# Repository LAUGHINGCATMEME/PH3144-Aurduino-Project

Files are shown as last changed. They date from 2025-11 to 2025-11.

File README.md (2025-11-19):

# How to use this repo

If someone wants to do the same then do it in the follwoing order: 
- Learn how each components works & why it's used
- Read datasheet
- Use the code, Schematics and report as a refrence, not as a guide.

### PS
Everything in this report is written by me other than the code for aurduinos. I have used grammerly as an assistant for grammer correction after completing the report entirely. Much of the code is written by AI though I woudn't suggest anyone to do the same.

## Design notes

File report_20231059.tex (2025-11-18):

\documentclass[%
sor,
jor,
amsmath,amssymb,
reprint,
]{revtex4-2}
\usepackage{rotating}
\usepackage{url}
\usepackage{hyperref}

\usepackage{amsmath, amssymb, amsfonts}
\usepackage{siunitx}
\usepackage{graphicx}

\begin{document}
\title{Arduino Project Report}

\author{Aumshree P. Shah - Group 19\\20231059}
\altaffiliation{\color{red}aumshree.pinkalbenshah@students.iiserpune.ac.in}
\date{\today}
\begin{abstract}
	\centering
	This report contains the motivation, idea, workings, troubleshooting, and final model of the Arduino project of Group-19.
\end{abstract}
\maketitle
\tableofcontents
\vspace*{\fill}
\pagebreak
\section{Motivation and Idea}
\subsection{Motivation}
Although given that the final product should be related to safety and address a safety issue, which my following concept does, I also tried to make something out of the ordinary, which motivates us to learn the workings of Arduino. 
\subsection{Concept}

My final concept was to make a \textit{Remote Controlled car, equipped with sensors to detect threats and monitor/neutralize them with a coil gun and cameras}. Though I went through many different concepts, like: Water gun with precise aim at fire, Car with automatic fire detection and neutralization, Dog in hostel detection and monitoring air quality levels, I decided to finalize on my former idea due to its complexity, budget constraints, and other reasons.

\section{Workings and Troubleshooting}
\subsection{Finding Resources}
The idea of \textit{RC car with Arduino} and \textit{Coilgun controlled by Arduino} separately has been worked on by many people many times. The diagrams and schematics of them, as well as the code, are available on the web and can be found easily, though there isn't much I could find that combines both of these ideas. Hence, although I had many of the resources readily available for my help, learning how it is done and making the changes was indeed very labour-intensive. I have made my own schematics for both the Transceiver and Receiver in the following section.
\subsection{Schematics}
First, we shall look at the transmitter schematic as shown in FIG-1.

\begin{sidewaysfigure}
	\centering
	
	\caption{Tramsitter Schematics}
	\label{fig:transmitter}
\end{sidewaysfigure}
Here we see the connection from the NRF module to the specific pins is done in such a way that allows the most compatibility. For example, in Arduino Nano, pins D13, D12, and D11 act as SCK, MISO, and MOSI, respectively. Other connections are arbitrary. The Joystick X and Y pins are connected to analog pins. The power is transmitted across the components in the following way: 
$$\text{Battery (6V)} \implies \text{Aurduino Nano (5V)} \implies \text{NRF Module regulator (3.3V)} \implies \text{NRF Module}$$\\
Now we will look at the receiver schematics shown in FIG-2. Here, although the NRF is connected in the same way to the Arduino, a few connections are made because of pin support; for example, the ENA pin is connected to D9 because only a few D pins support PWM, which the L298 driver requires. The power is transmitted across the components in the following way: 

\begin{align*}
	\text{Battery (11.1V)} \implies &\text{L298N Motor Driver(11.1)} \implies \text{4 x Motors}\\
					&\text{L298N Motor Driver(5V)} \implies \text{Aurduino Nano (5V))} \implies \text{NRF Module w/Regulator}
\end{align*}
\begin{sidewaysfigure}
	\centering
	
	\caption{Reciver Schematics}
	\label{fig:reciver}
\end{sidewaysfigure}

\subsection{How I made it}
Since my main goal was to make a RC-controlled car, my first step was to make two different Arduinos communicate. For the communication, I decided to use \textbf{NRF24L01+PA+LNA SMA Antenna Wireless Transceiver communication module} as the price difference between the alternatives v/s this was not much, whereas the range was significantly higher. This module operates at 3.3V, to regulate it, I used \textbf{NRF24L01 regulator}, which regulates the logic voltage. I used this regulator after trial and error to regulate the voltage, which will be discussed in a later section.\\

For the motors, I use \textbf{4 x 300RPM PO Motors} since 300 RPM seemed in the proper range for a car with wheels of diameter $\approx 7\si{cm}$. These motors run on 12V. \\

For the battery, in the transmitter I used \textbf{4 x 1.5V alkaline battery} giving 6V, which is given to Arduino $V_{in}$ pin. The Arduino has an internal regulator that regulates it to 5V. The Arduino provides power to the NRF regulator.\\ 

In the receiver, I used \textbf{3 x 3.7V LiOH battery}, which is rechargeable. The reason for using them will be discussed in the next section. This produces a voltage of $\approx 11$V, which is given to \textbf{L298N Motor Driver}, which runs the motors. The L298N has an internal regulator that regulates the voltage to 5V, which powers the Arduino.\\

A phone holder is added to the back, which can function as many things. \\

In the receiver, the NRF is also powered by Arduino through a regulator. Almost all of the connections are made using \textbf{Jumper wires of different types} and \textbf{Breadboard}. Some do use \textbf{High Gauge copper wires} to supply high current to motors.\\
\subsection{Issues I faced - and how I solved them}
\subsubsection{Battery unable to provide required power}
Initially, I used \textbf{9V alkaline battery}. A single 9V battery was unable to provide power to the motors, so I used 4 of them in parallel. Although this made the car functional, it had many disadvantages. For example, it was unrechargeable, even 4 of them in series were sometimes not able to provide enough current, and the motors were rated for 12V, so 9V batteries weren't running the motors at maximum capacity.
\subsubsection{Search for a proper chassis for a car}
I needed a strong base for my car. A cardboard couldn't hold its weight. A proper chassis was really hard to find, and after some trial and error, I finally settled on a small black metal box, which I found in a mechanic's box. 
\subsubsection{Regulation of NRF module}
This was a really big issue when I first started testing, since to make anything out of this project, I first had to communicate between two Arduinos. The NRF module operates at 3.3V, and the Arduino logic is 5V. I had to use some kind of way to regulate it. First, I used resistor dividers, but it turned out that they caused a high level of signal disturbance. Then I used voltage regulators, these kind of worked, but there was always some kind of issue which made the modules unable to communicate. Also, since the NRF module needs a large supply of current peaks, my initial tests were without parallel capacitors, so no matter how I regulated the voltage, the module was unable to communicate. This was finally resolved by using a dedicated NRF voltage regulator, which was compact, cheap, and did everything we needed.
\subsubsection{Fused and non-working components}
Many of the components got fused while I were working on them, includes but not limited to: Arduino nano, an NRF module, etc. To prevent this from happening on other components, I found the following helpful: Not soldering components directly to the other components, using voltage limiters, reading the datasheet (obvious, but I initially ignored this), and by not shorting the components (obvious, but that's how my nano got fused).
\subsubsection{Weight, Speed Structure and Battery life}
For weight, Speed, and battery life, all these issues were solved by LiOH batteries. To fix the motor ot the chassis, I used Feviquick, which worked really well and was able to carry a good amount of weight on the car. Other components were fixed by hot glue, and the final structure was made after many trials and errors.\\

\section{Result and final product}
The car and the controller looked like this after completion:\\

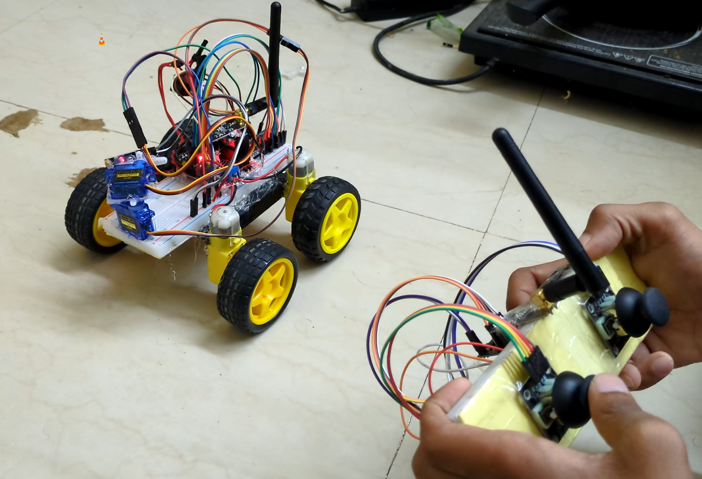
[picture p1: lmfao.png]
\linebreak

and video's of this running is uploaded on youtube as refrenced in the next refrence section. 
\vspace{1cm}
\hrule
\vfill
\pagebreak

\bibliographystyle{apsrev4-2}  % or apsrev4-1, prsty, etc.
\nocite{*}
\bibliography{resource}

\end{document}

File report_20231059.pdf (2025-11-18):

## Arduino Project Report

Aumshree P. Shah - Group 19 20231059a)

(Dated: 18 November 2025)
Synopsis

This report contains the motivation, idea, workings, troubleshooting, and final model of the Arduino project of Group-19.

CONTENTS

I. Motivation and Idea | 2
A. Motivation | 2
B. Concept | 2
II. Workings and Troubleshooting | 2
A. Finding Resources | 2
B. Schematics | 2
C. How I made it | 5
D. Issues I faced - and how I solved them | 5
1. Battery unable to provide required power | 5
2. Search for a proper chassis for a car | 5
3. Regulation of NRF module | 5
4. Fused and non-working components | 6
5. Weight, Speed Structure and Battery life | 6
III. Result and final product | 6
References | 7

a)aumshree.pinkalbenshah@students.iiserpune.ac.in

I. MOTIVATION AND IDEA
A. Motivation

Although given that the final product should be related to safety and address a safety issue, which my following concept does, I also tried to make something out of the ordinary, which motivates us to learn the workings of Arduino.

B. Concept

My final concept was to make a Remote Controlled car, equipped with sensors to detect threats and monitor/neutralize them with a coil gun and cameras. Though I went through many different concepts, like: Water gun with precise aim at fire, Car with automatic fire detection and neutralization, Dog in hostel detection and monitoring air quality levels, I decided to finalize on my former idea due to its complexity, budget constraints, and other reasons.

II. WORKINGS AND TROUBLESHOOTING

A. Finding Resources

The idea of RC car with Arduino and Coilgun controlled by Arduino separately has been worked on by many people many times. The diagrams and schematics of them, as well as the code, are available on the web and can be found easily, though there isn’t much I could find that combines both of these ideas. Hence, although I had many of the resources readily available for my help, learning how it is done and making the changes was indeed very labour-intensive. I have made my own schematics for both the Transceiver and Receiver in the following section.

B. Schematics

First, we shall look at the transmitter schematic as shown in FIG-1.
Here we see the connection from the NRF module to the specific pins is done in such a way that allows the most compatibility. For example, in Arduino Nano, pins D13, D12, and D11 act as SCK, MISO, and MOSI, respectively. Other connections are arbitrary. The Joystick X and Y pins are connected to analog pins. The power is transmitted across the components in the following way:

Battery (6V) =⇒ Aurduino Nano (5V) =⇒ NRF Module regulator (3.3V) =⇒ NRF Module

Now we will look at the receiver schematics shown in FIG-2. Here, although the NRF is connected in the same way to the Arduino, a few connections are made because of pin support; for example, the ENA pin is connected to D9 because only a few D pins support PWM, which the L298 driver requires. The power is transmitted across the components in the following way:

Battery (11.1V) =⇒ L298N Motor Driver(11.1) =⇒ 4 x Motors
L298N Motor Driver(5V) =⇒ Aurduino Nano (5V)) =⇒ NRF Module w/Regulator

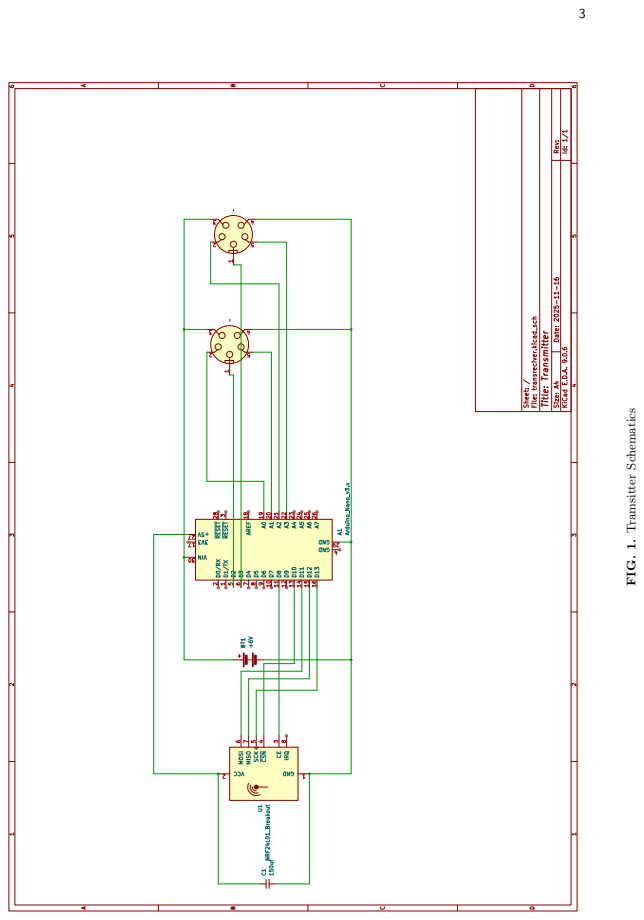
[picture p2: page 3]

FIG. 1. Tramsitter Schematics

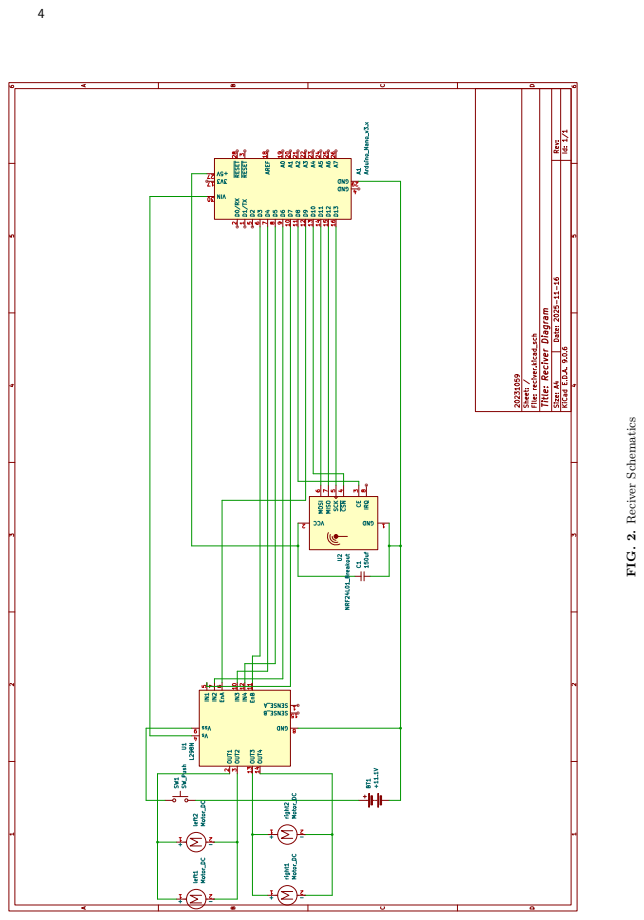
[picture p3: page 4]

FIG. 2. Reciver Schematics

C. How I made it

Since my main goal was to make a RC-controlled car, my first step was to make two different Arduinos communicate. For the communication, I decided to use NRF24L01+PA+LNA SMA Antenna Wireless Transceiver communication module as the price difference between the alternatives v/s this was not much, whereas the range was significantly higher. This module operates at 3.3V, to regulate it, I used NRF24L01 regulator, which regulates the logic voltage. I used this regulator after trial and error to regulate the voltage, which will be discussed in a later section.

For the motors, I use 4 x 300RPM PO Motors since 300 RPM seemed in the proper range for a car with wheels of diameter ≈ 7cm. These motors run on 12V.

For the battery, in the transmitter I used 4 x 1.5V alkaline battery giving 6V, which is given to Arduino Vin pin. The Arduino has an internal regulator that regulates it to 5V. The Arduino provides power to the NRF regulator.

In the receiver, I used 3 x 3.7V LiOH battery, which is rechargeable. The reason for using them will be discussed in the next section. This produces a voltage of ≈ 11V, which is given to L298N Motor Driver, which runs the motors. The L298N has an internal regulator that regulates the voltage to 5V, which powers the Arduino.

A phone holder is added to the back, which can function as many things.

In the receiver, the NRF is also powered by Arduino through a regulator. Almost all of the connections are made using Jumper wires of different types and Breadboard. Some do use High Gauge copper wires to supply high current to motors.

D. Issues I faced - and how I solved them

### 1. Battery unable to provide required power

Initially, I used 9V alkaline battery. A single 9V battery was unable to provide power to the motors, so I used 4 of them in parallel. Although this made the car functional, it had many disadvantages. For example, it was unrechargeable, even 4 of them in series were sometimes not able to provide enough current, and the motors were rated for 12V, so 9V batteries weren’t running the motors at maximum capacity.

### 2. Search for a proper chassis for a car

I needed a strong base for my car. A cardboard couldn’t hold its weight. A proper chassis was really hard to find, and after some trial and error, I finally settled on a small black metal box, which I found in a mechanic’s box.

### 3. Regulation of NRF module

This was a really big issue when I first started testing, since to make anything out of this project, I first had to communicate between two Arduinos. The NRF module operates at 3.3V, and the Arduino logic is 5V. I had to use some kind of way to regulate it. First, I used resistor dividers, but it turned out that they caused a high level of signal disturbance. Then I used voltage regulators, these kind of worked, but there was always some kind of issue which made the modules unable to communicate. Also, since the NRF module needs a large supply of current peaks, my initial tests were without parallel capacitors, so no matter how I regulated the voltage, the module was unable to communicate. This was finally resolved by using a dedicated NRF voltage regulator, which was compact, cheap, and did everything we needed.

### 4. Fused and non-working components

Many of the components got fused while I were working on them, includes but not limited to: Arduino nano, an NRF module, etc. To prevent this from happening on other components, I found the following helpful: Not soldering components directly to the other components, using voltage limiters, reading the datasheet (obvious, but I initially ignored this), and by not shorting the components (obvious, but that’s how my nano got fused).

### 5. Weight, Speed Structure and Battery life

For weight, Speed, and battery life, all these issues were solved by LiOH batteries. To fix the motor ot the chassis, I used Feviquick, which worked really well and was able to carry a good amount of weight on the car. Other components were fixed by hot glue, and the final structure was made after many trials and errors.

III. RESULT AND FINAL PRODUCT

The car and the controller looked like this after completion:

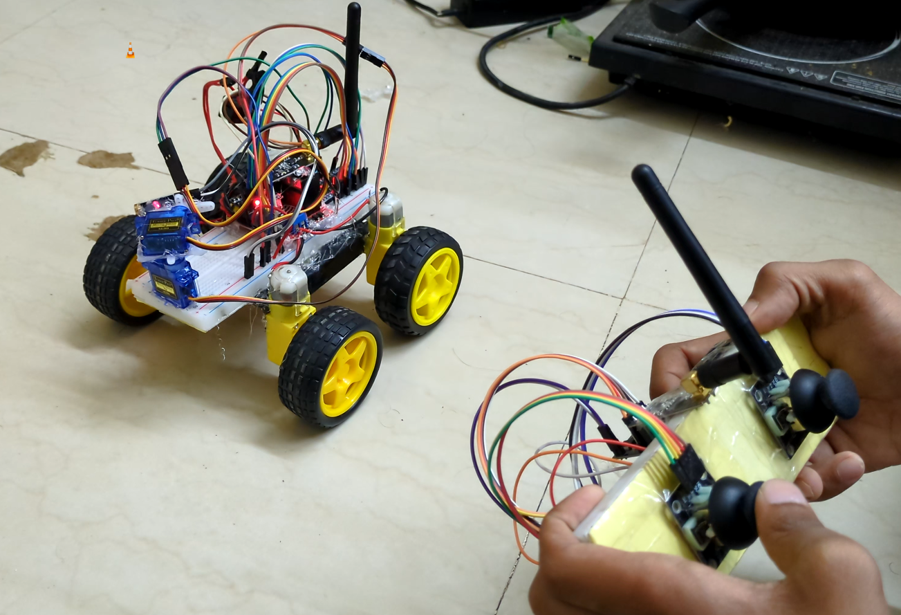
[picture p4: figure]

and video’s of this running is uploaded on youtube as refrenced in the next refrence section.

REFERENCES

Lauging-Cat-Meme, | Aurduino | Group-19 | Code, | https://github.com/LAUGHINGCATMEME/
PH3144-Aurduino-Project (https://github.com/LAUGHINGCATMEME/PH3144-Aurduino-Project) (2025), [Online; accessed 16-Nov-2025].
Dejan, How to make Aurduino Transmitter and reciver, https://howtomechatronics.com/projects/diy-arduino-rc-transmitter/ (https://howtomechatronics.com/projects/diy-arduino-rc-transmitter/) (2020), [Online; accessed 16-Nov-2025].
Laughing-Cat-Meme, Demo of RC Car, https://youtu.be/8HlMw1vrnL0 (2025a), [Online; accessed 18-Nov-2025].
Laughing-Cat-Meme, Demo of RC Car - Car POV, youtu.be/yLEg9JWuXcM (2025b), [Online; accessed 18-Nov-2025].

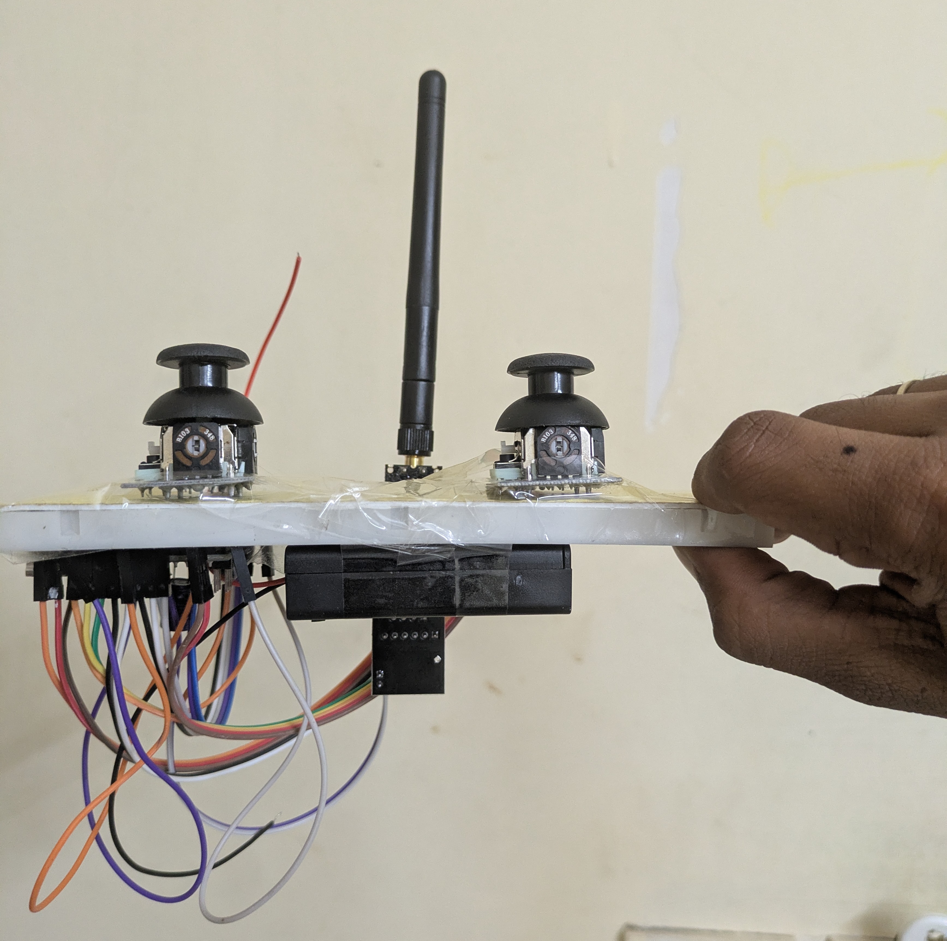
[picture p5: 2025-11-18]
transmitter.jpg

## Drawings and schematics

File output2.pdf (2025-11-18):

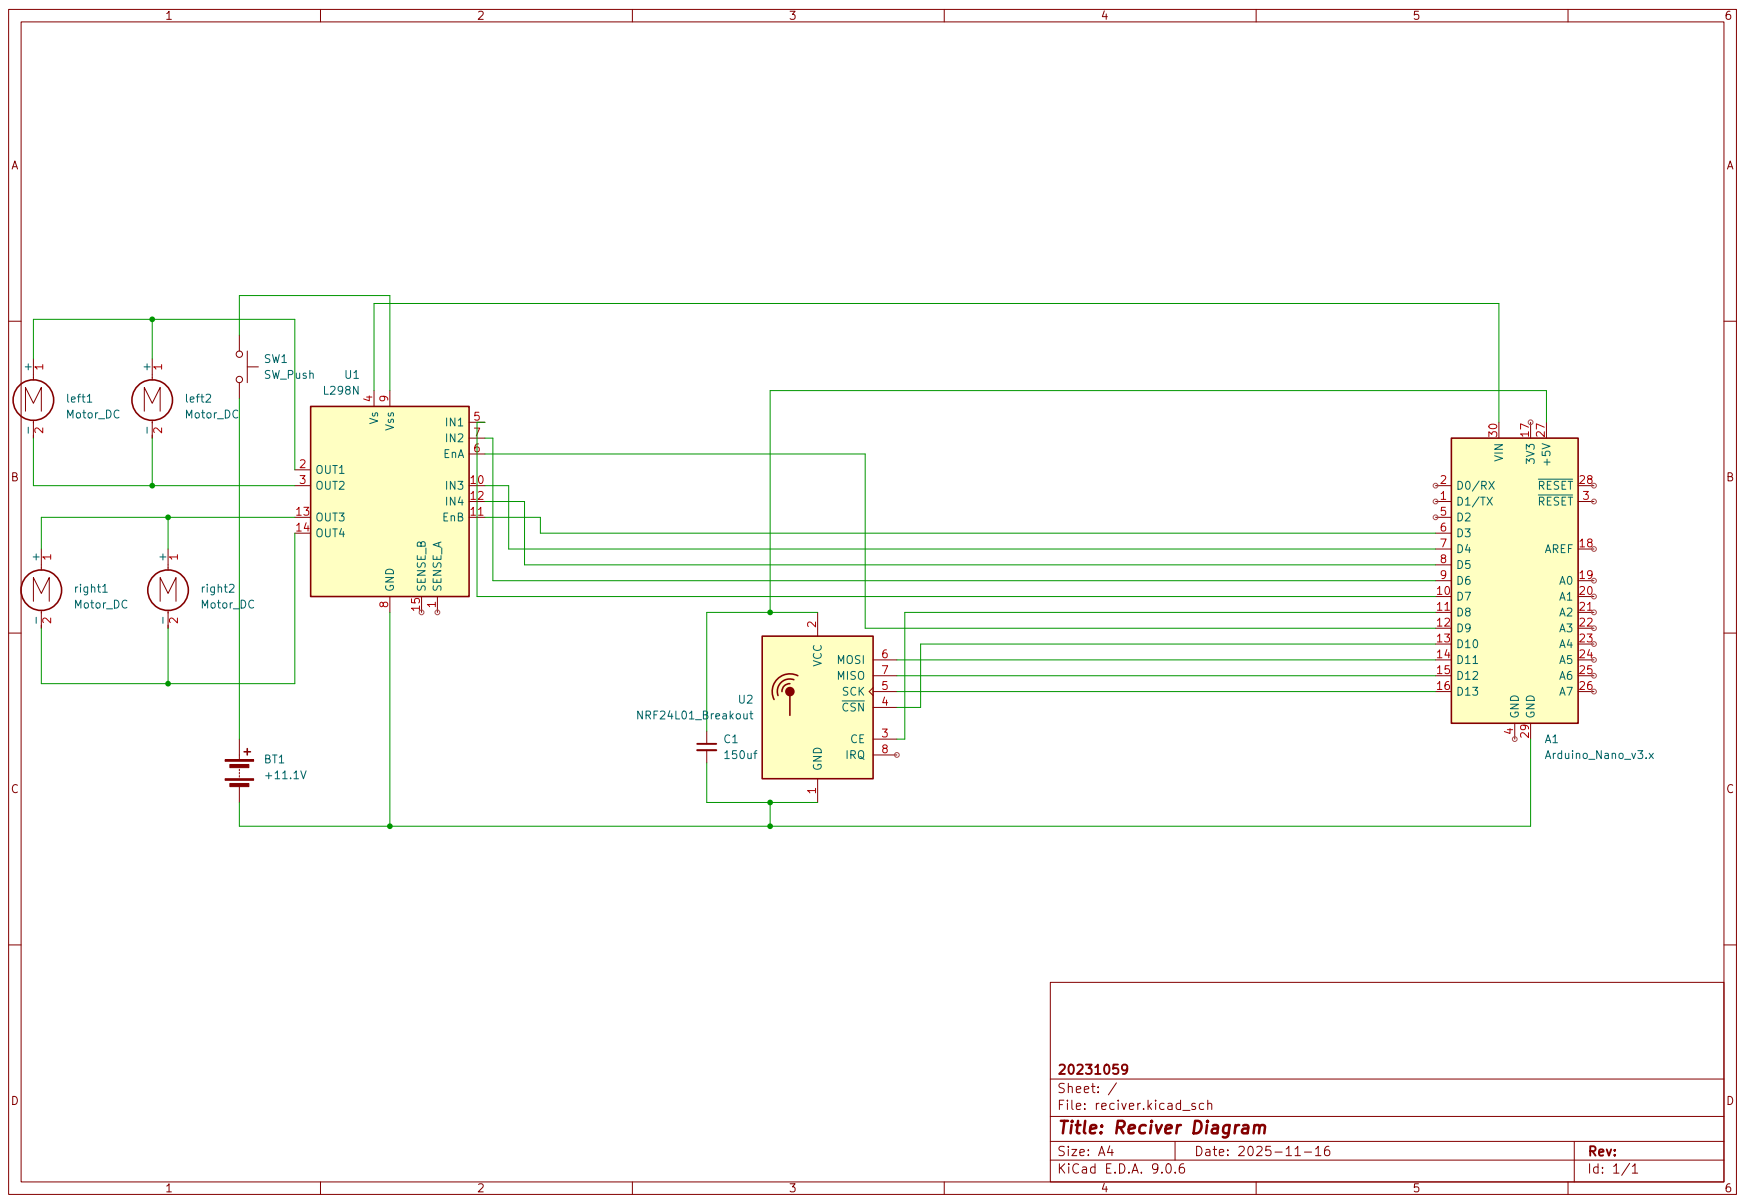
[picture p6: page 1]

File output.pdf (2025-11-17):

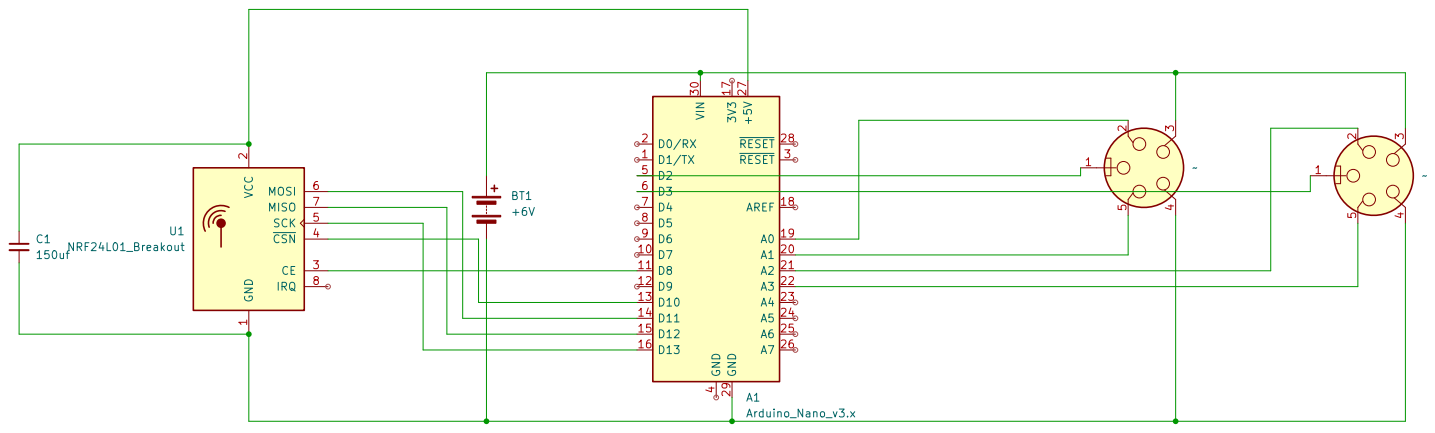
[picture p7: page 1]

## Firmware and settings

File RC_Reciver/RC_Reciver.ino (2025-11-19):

/* Receiver for nRF24L01 -> L298N (4 wheels)
   - Expects Telemetry struct packed by the transmitter (j1_x, j1_y, j1_sw, j2_x, j2_y, j2_sw)
   - Uses joystick2 (j2_x, j2_y) to control motion:
       j2_y = forward/back ( -100..100 )
       j2_x = turn left/right ( -100..100 )
   - Differential mixing: left = y + x, right = y - x
   - IMPORTANT: ensure motor IN pins do NOT collide with NRF CE/CSN (D5/D6).
   - Wiring assumptions (edit if you rewire):
       NRF: CE=D8, CSN=D10, MOSI=D11, MISO=D12, SCK=D13
       L298N: IN1=D7, IN2=D6, ENA=D9 (left)
              IN3=D4, IN4=D5, ENB=D3 (right)
*/
/*
  Full sketch: nRF24L01 receiver -> L298N (4 wheels) + 2 servos (A0/A1).
  - Telemetry struct expected from transmitter: j1_x, j1_y, j1_sw, j2_x, j2_y, j2_sw
  - Joystick 1 (j1_x -> servoX on A0, j1_y -> servoY on A1)
    Behavior: when axis > JOY_THRESHOLD, the corresponding servo TARGET increases
              by SERVO_STEP degrees every SERVO_STEP_MS ms.
              when axis < -JOY_THRESHOLD, target decreases similarly.
              when axis within +/- JOY_THRESHOLD, target is NOT changed (held).
  - Joystick 2 (j2_x/j2_y) still drives differential motor mixing as before.
  - JOY2 button (j2_sw) output mirrored on D2.
  - NOTE: servo motors are attached to A0/A1. If servos draw too much current,
          use a separate 5V supply with common ground.
*/

// Libraries
#include <SPI.h>
#include <RF24.h>
#include <Servo.h>
// ----------------- RADIO -----------------
RF24 radio(8, 10);
const uint64_t pipe = 0xE8E8F0F0E1LL;

// ----------------- MOTOR PINS -----------------
const uint8_t IN1_PIN = 7;
const uint8_t IN2_PIN = 6;
const uint8_t ENA_PIN = 5;

const uint8_t IN3_PIN = 4;
const uint8_t IN4_PIN = 9;
const uint8_t ENB_PIN = 3;

// ----------------- SAFETY / TUNING -----------------
const unsigned long TIMEOUT_MS = 250;
const uint8_t SMOOTH_FACTOR = 4;
const int MAX_INPUT = 100;
const int PWM_MAX = 255;

// ----- NEW: turn scaling and joystick button output -----
const float TURN_SCALE = 0.8f;
const uint8_t JOY2_BUTTON_OUT_PIN = 2;  // NEW: D2 outputs HIGH/LOW based on j2_sw

// ----------------- Servos -----------------
const uint8_t SERVO_PINX = A0; // servoX (controls X axis)
const uint8_t SERVO_PINY = A1; // servoY (controls Y axis)
Servo servoX;
Servo servoY;

// Servo motion tuning (change these as you like)
const int JOY_THRESHOLD = 12;         // "certain value" threshold (±). Must exceed to change target.
const uint8_t SERVO_STEP = 1;         // degrees to change per step (1 = very slow)
const unsigned long SERVO_STEP_MS = 50; // ms between steps (increase -> slower motion)
 // NOTE: SERVO_STEP + SERVO_STEP_MS determine angular speed.


struct Telemetry {
  int16_t j1_x;
  int16_t j1_y;
  uint8_t j1_sw;
  int16_t j2_x;
  int16_t j2_y;
  uint8_t j2_sw;
};

unsigned long last_rx = 0;
int currentLeftPWM = 0, currentRightPWM = 0;

// servo persistent targets & positions
int targetX = 90;   // stored target for X servo (0..180)
int targetY = 90;   // stored target for Y servo (0..180)
int posX = 90;      // current actual position (angle) written to servoX
int posY = 90;      // current actual position written to servoY
unsigned long lastServoStep = 0;

void setup() {
  pinMode(IN1_PIN, OUTPUT);
  pinMode(IN2_PIN, OUTPUT);
  pinMode(ENA_PIN, OUTPUT);

  pinMode(IN3_PIN, OUTPUT);
  pinMode(IN4_PIN, OUTPUT);
  pinMode(ENB_PIN, OUTPUT);

  // NEW: joystick 2 button output
  pinMode(JOY2_BUTTON_OUT_PIN, OUTPUT);
  digitalWrite(JOY2_BUTTON_OUT_PIN, LOW); // default LOW

  Serial.begin(9600);
  delay(50);
  Serial.println(F("RX Motor Controller starting"));

  if (!radio.begin()) {
    Serial.println(F("radio.begin failed - check wiring and 3.3V power"));
    while (1) { delay(200); }
  }

  radio.setPALevel(RF24_PA_LOW);
  radio.setDataRate(RF24_1MBPS);
  radio.openReadingPipe(1, pipe);
  radio.startListening();
  radio.enableDynamicPayloads();
  radio.setAutoAck(true);

  last_rx = millis();
  stopMotors();
  Serial.println(F("RX ready, listening..."));
  posX = targetX = 90;
  posY = targetY = 90;
  servoX.attach(SERVO_PINX);
  servoY.attach(SERVO_PINY);
  servoX.write(posX);
  servoY.write(posY);

}

int mapToPWM(int v) {
  v = constrain(v, -MAX_INPUT, MAX_INPUT);
  return (v * PWM_MAX) / MAX_INPUT;
}

// set a motor side: speed in -255..255
void setMotorSide(uint8_t inA, uint8_t inB, uint8_t enPin, int speed) {
  if (speed > 0) {
    digitalWrite(inA, HIGH);
    digitalWrite(inB, LOW);
    analogWrite(enPin, constrain(speed, 0, PWM_MAX));
  } else if (speed < 0) {
    digitalWrite(inA, LOW);
    digitalWrite(inB, HIGH);
    analogWrite(enPin, constrain(-speed, 0, PWM_MAX));
  } else {
    digitalWrite(inA, LOW);
    digitalWrite(inB, LOW);
    analogWrite(enPin, 0);
  }
}

void stopMotors() {
  setMotorSide(IN1_PIN, IN2_PIN, ENA_PIN, 0);
  setMotorSide(IN3_PIN, IN4_PIN, ENB_PIN, 0);
  currentLeftPWM = currentRightPWM = 0;
}

void loop() {
  // radio + telemetry handling
  if (radio.available()) {
    uint8_t len = radio.getDynamicPayloadSize();
    if (len == 0 || len > sizeof(Telemetry)) {
      radio.flush_rx();
      Serial.print(F("RX: bad payload size "));
      Serial.println(len);
    } else {
      Telemetry t;
      memset(&t, 0, sizeof(t));
      radio.read(&t, len);
      last_rx = millis();

      // ---------------- Driving logic (unchanged) ----------------
      int jx = constrain((int)t.j2_x, -MAX_INPUT, MAX_INPUT);
      int jy = -constrain((int)t.j2_y, -MAX_INPUT, MAX_INPUT);

      float speedFactor = 1.0f - (abs(jy) / (float)MAX_INPUT) * 0.4f;
      if (speedFactor < 0.6f) speedFactor = 0.6f;
      int scaledJx = (int)round(jx * TURN_SCALE * speedFactor);

      int leftVal = constrain(jy + scaledJx, -MAX_INPUT, MAX_INPUT);
      int rightVal = constrain(jy - scaledJx, -MAX_INPUT, MAX_INPUT);

      int targetLeft = mapToPWM(leftVal);
      int targetRight = mapToPWM(rightVal);

      if (SMOOTH_FACTOR <= 1) {
        currentLeftPWM = targetLeft;
        currentRightPWM = targetRight;
      } else {
        currentLeftPWM += (targetLeft - currentLeftPWM) / SMOOTH_FACTOR;
        currentRightPWM += (targetRight - currentRightPWM) / SMOOTH_FACTOR;
      }

      setMotorSide(IN1_PIN, IN2_PIN, ENA_PIN, currentLeftPWM);
      setMotorSide(IN3_PIN, IN4_PIN, ENB_PIN, currentRightPWM);

      // JOY2 button reflect on D2
      digitalWrite(JOY2_BUTTON_OUT_PIN, t.j2_sw ? HIGH : LOW);

      // ---------------- Servo target-maker logic (joystick 1 controls targets) ----------------
      // j1_x controls targetX (servoX), j1_y controls targetY (servoY)
      int j1x = constrain((int)t.j1_x, -MAX_INPUT, MAX_INPUT);
      int j1y = constrain((int)t.j1_y, -MAX_INPUT, MAX_INPUT);

      unsigned long now = millis();

      // Update targetX if joystick X deflection exceeds threshold
      if (j1x > JOY_THRESHOLD) {
        // increase targetX slowly
        if (now - lastServoStep >= SERVO_STEP_MS) {
          lastServoStep = now;
          targetX = constrain(targetX + SERVO_STEP, 0, 180);
        }
      } else if (j1x < -JOY_THRESHOLD) {
        // decrease targetX slowly
        if (now - lastServoStep >= SERVO_STEP_MS) {
          lastServoStep = now;
          targetX = constrain(targetX - SERVO_STEP, 0, 180);
        }
      }
      // If within threshold, do NOT change targetX (held value)

      // Update targetY similarly (independent)
      if (j1y > JOY_THRESHOLD) {
        if (now - lastServoStep >= SERVO_STEP_MS) {
          lastServoStep = now;
          targetY = constrain(targetY + SERVO_STEP, 0, 180);
        }
      } else if (j1y < -JOY_THRESHOLD) {
        if (now - lastServoStep >= SERVO_STEP_MS) {
          lastServoStep = now;
          targetY = constrain(targetY - SERVO_STEP, 0, 180);
        }
      }
      // If within threshold, do NOT change targetY

      // ---------------- Move servos slowly toward stored targets ----------------
      // We'll step posX/posY by at most SERVO_STEP on each SERVO_STEP_MS tick (already gated above).
      // This ensures smooth slow motion.
      // Note: using same lastServoStep for both axes means the step cadence is shared;
      // if you prefer separate rates, create lastServoStepX/lastServoStepY.
      if (posX < targetX) {
        posX = min(posX + SERVO_STEP, targetX);
        servoX.write(posX);
      } else if (posX > targetX) {
        posX = max(posX - SERVO_STEP, targetX);
        servoX.write(posX);
      }

      if (posY < targetY) {
        posY = min(posY + SERVO_STEP, targetY);
        servoY.write(posY);
      } else if (posY > targetY) {
        posY = max(posY - SERVO_STEP, targetY);
        servoY.write(posY);
      }

      // ---------------- Debug print ----------------
      Serial.print(F("J1 x=")); Serial.print(j1x);
      Serial.print(F(" y=")); Serial.print(j1y);
      Serial.print(F(" | tgtX=")); Serial.print(targetX);
      Serial.print(F(" tgtY=")); Serial.print(targetY);
      Serial.print(F(" | posX=")); Serial.print(posX);
      Serial.print(F(" posY=")); Serial.print(posY);
      Serial.print(F(" | motors L=")); Serial.print(currentLeftPWM);
      Serial.print(F(" R=")); Serial.print(currentRightPWM);
      Serial.println();
    }
  } else {
    // radio not available: check timeout
    if (millis() - last_rx > TIMEOUT_MS) {
      stopMotors();
      // keep targets unchanged; servos remain at current pos
    }
  }

  delay(5);
}

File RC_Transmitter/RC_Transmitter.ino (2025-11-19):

/* Receiver for nRF24L01 -> L298N (4 wheels) + 2 servos (perpendicular axes)
   - Expects Telemetry struct packed by the transmitter (j1_x, j1_y, j1_sw, j2_x, j2_y, j2_sw)
   - Uses joystick2 (j2_x, j2_y) to control motion:
       j2_y = forward/back ( -100..100 )
       j2_x = turn left/right ( -100..100 )
   - Differential mixing: left = y + x, right = y - x
   - Two servos: one assigned to X-axis, one to Y-axis (perpendicular).
     Only one servo is actively driven at a time (the axis with larger deflection).
   - JOY2 pushbutton (j2_sw) is reflected on D2 (HIGH when pressed).
   - NOTE: left PWM (ENA) moved to D5 to avoid Timer1 conflicts with Servo library.
*/

#include <SPI.h>
#include <RF24.h>
#include <Servo.h>

// ----------------- RADIO -----------------
RF24 radio(8, 10);
const uint64_t pipe = 0xE8E8F0F0E1LL;

// ----------------- MOTOR PINS ----------------- (adjusted ENA -> D5)
const uint8_t IN1_PIN = 7;   // Left motor direction A
const uint8_t IN2_PIN = 6;   // Left motor direction B
const uint8_t ENA_PIN = 5;   // Left PWM (moved from D9 -> D5 to avoid Timer1 conflict)

const uint8_t IN3_PIN = 4;   // Right motor direction A
const uint8_t IN4_PIN = 9;   // Right motor direction B (moved from D5 -> D9)
const uint8_t ENB_PIN = 3;   // Right PWM

// ----------------- SAFETY / TUNING -----------------
const unsigned long TIMEOUT_MS = 250;
const uint8_t SMOOTH_FACTOR = 4;
const int MAX_INPUT = 100;
const int PWM_MAX = 255;

// ----- NEW: turn scaling and joystick button output -----
const float TURN_SCALE = 0.8f;
const uint8_t JOY2_BUTTON_OUT_PIN = 2;  // D2 outputs HIGH/LOW based on j2_sw

// ----- Servos -----
const uint8_t SERVO_X_PIN = A0;   // servo that responds to X axis (use analog pins as digital)
const uint8_t SERVO_Y_PIN = A1;   // servo that responds to Y axis
const int SERVO_DEADZONE = 8;     // joystick deadzone (0..100)
Servo servoX;
Servo servoY;
bool servoX_attached = false;
bool servoY_attached = false;

// Telemetry struct must match the transmitter
struct Telemetry {
  int16_t j1_x;
  int16_t j1_y;
  uint8_t j1_sw;
  int16_t j2_x;
  int16_t j2_y;
  uint8_t j2_sw;
};

unsigned long last_rx = 0;
int currentLeftPWM = 0, currentRightPWM = 0;

void setup() {
  // motor pins
  pinMode(IN1_PIN, OUTPUT);
  pinMode(IN2_PIN, OUTPUT);
  pinMode(ENA_PIN, OUTPUT);

  pinMode(IN3_PIN, OUTPUT);
  pinMode(IN4_PIN, OUTPUT);
  pinMode(ENB_PIN, OUTPUT);

  // joystick 2 button output
  pinMode(JOY2_BUTTON_OUT_PIN, OUTPUT);
  digitalWrite(JOY2_BUTTON_OUT_PIN, LOW); // default LOW

  Serial.begin(9600);
  delay(50);
  Serial.println(F("RX Motor+Servo Controller starting"));

  if (!radio.begin()) {
    Serial.println(F("radio.begin failed - check wiring and 3.3V power"));
    while (1) { delay(200); }
  }

  radio.setPALevel(RF24_PA_LOW);
  radio.setDataRate(RF24_1MBPS);
  radio.openReadingPipe(1, pipe);
  radio.startListening();
  radio.enableDynamicPayloads();
  radio.setAutoAck(true);

  last_rx = millis();
  stopMotors();

  // Ensure servos start detached for lowest current draw
  if (servoX_attached) { servoX.detach(); servoX_attached = false; }
  if (servoY_attached) { servoY.detach(); servoY_attached = false; }

  Serial.println(F("RX ready, listening..."));
}

// map -100..100 to -255..255
int mapToPWM(int v) {
  v = constrain(v, -MAX_INPUT, MAX_INPUT);
  return (v * PWM_MAX) / MAX_INPUT;
}

// set a motor side: speed in -255..255
void setMotorSide(uint8_t inA, uint8_t inB, uint8_t enPin, int speed) {
  if (speed > 0) {
    digitalWrite(inA, HIGH);
    digitalWrite(inB, LOW);
    analogWrite(enPin, constrain(speed, 0, PWM_MAX));
  } else if (speed < 0) {
    digitalWrite(inA, LOW);
    digitalWrite(inB, HIGH);
    analogWrite(enPin, constrain(-speed, 0, PWM_MAX));
  } else {
    // stop/coast
    digitalWrite(inA, LOW);
    digitalWrite(inB, LOW);
    analogWrite(enPin, 0);
  }
}

void stopMotors() {
  setMotorSide(IN1_PIN, IN2_PIN, ENA_PIN, 0);
  setMotorSide(IN3_PIN, IN4_PIN, ENB_PIN, 0);
  currentLeftPWM = currentRightPWM = 0;
}

// Map -100..100 -> 0..180 servo angle
int axisToServoAngle(int v) {
  v = constrain(v, -MAX_INPUT, MAX_INPUT);
  return map(v, -MAX_INPUT, MAX_INPUT, 0, 180);
}

void attachServoXIfNeeded() {
  if (!servoX_attached) {
    servoX.attach(SERVO_X_PIN);
    servoX_attached = true;
    // short settle delay
    delay(10);
  }
}
void detachServoXIfNeeded() {
  if (servoX_attached) {
    servoX.detach();
    servoX_attached = false;
  }
}
void attachServoYIfNeeded() {
  if (!servoY_attached) {
    servoY.attach(SERVO_Y_PIN);
    servoY_attached = true;
    delay(10);
  }
}
void detachServoYIfNeeded() {
  if (servoY_attached) {
    servoY.detach();
    servoY_attached = false;
  }
}
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
